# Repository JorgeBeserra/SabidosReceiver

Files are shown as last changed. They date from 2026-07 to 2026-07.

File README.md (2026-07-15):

# SabidosReceiver

Projeto de receptor e processador de áudio multicanal baseado no **PT2322-S**, controlado por um **ESP32**.

## Ferramenta

O projeto principal está em formato **KiCad 10**:

- `SabidosReceiver.kicad_pro`
- `SabidosReceiver.kicad_sch`
- `SabidosReceiver.kicad_pcb`

Abra sempre o arquivo `SabidosReceiver.kicad_pro` para manter o esquemático e a PCB associados ao mesmo projeto.

## Situação da migração

O projeto foi renomeado de `SabVolAudio` para `SabidosReceiver`. Ainda existem arquivos e identificadores legados preservados no repositório para conferência durante a migração.

Antes de removê-los definitivamente, é necessário confirmar que todas as folhas hierárquicas e todos os componentes foram convertidos corretamente para o formato atual do KiCad.

## Cuidados antes da fabricação

1. Confirmar fisicamente o encapsulamento do PT2322-S e validar o footprint em escala 1:1.
2. Abrir e salvar todas as folhas hierárquicas no KiCad 10.
3. Executar o ERC no esquemático.
4. Atualizar a PCB a partir do esquemático e revisar cada inclusão ou remoção proposta.
5. Executar o DRC na PCB.
6. Conferir a região da antena do ESP32 e manter cobre afastado.
7. Conferir polaridade dos capacitores eletrolíticos e pinagem de todos os conectores.
8. Gerar novos Gerbers somente depois da validação.

## Organização recomendada

- Arquivos `.kicad_*`: fontes atuais do projeto.
- Bibliotecas locais: símbolos e footprints necessários para abrir o projeto em outro computador.
- Modelos 3D: devem usar caminhos relativos com `${KIPRJMOD}`.
- Gerbers, backups, netlists e preferências locais não devem ser versionados.

## Observação importante

Os arquivos legados não devem ser apagados sem comparação visual com o esquemático atual, porque algumas folhas convertidas aparecem vazias e podem ainda depender do conteúdo antigo.

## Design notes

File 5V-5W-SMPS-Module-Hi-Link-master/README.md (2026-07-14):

# 5V-5W-SMPS-Module-Hi-Link
Schematic and Footptint in Kicad

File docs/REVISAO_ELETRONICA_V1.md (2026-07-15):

# Revisão eletrônica e PCB — SabidosReceiver V1

Este documento registra as alterações técnicas recomendadas antes da fabricação.

## Contexto de uso

O equipamento será usado em ambiente residencial como processador de áudio para home theater. A TV fornecerá áudio digital S/PDIF a um conversor externo, e as saídas analógicas multicanal desse conversor entrarão no SabidosReceiver.

A placa será alimentada por fonte DC regulada de 12 V para uso interno. Não é necessário projetar para transientes automotivos, load dump ou ambiente veicular.

## Prioridade crítica

### PT2322-S

- Confirmar o encapsulamento físico e a pinagem do componente disponível.
- O footprint somente deve ser substituído depois da medição do CI real.
- Imprimir o footprint em escala 1:1 e conferir o componente sobre o papel.

### Folhas hierárquicas

- `display.kicad_sch` e `Ir.kicad_sch` estão vazias na versão atual.
- Não atualizar a PCB a partir do esquemático enquanto não for decidido se esses circuitos serão recuperados dos arquivos legados ou removidos.

## Alimentação

- Manter a fonte chaveada LM2596 fisicamente afastada das entradas e saídas de áudio.
- Criar retorno de corrente curto entre entrada de 12 V, LM2596 e conector de alimentação.
- Não permitir que o retorno do conversor atravesse a região do PT2322-S.
- Adicionar desacoplamento local próximo ao PT2322-S: 100 nF cerâmico em paralelo com 10 µF na alimentação de 8 V.
- Adicionar desacoplamento próximo ao ESP32: 100 nF cerâmico e capacitor de reserva entre 220 µF e 470 µF na linha de 5 V.
- Manter o LM78M08 com área de cobre suficiente para dissipação térmica.
- Priorizar fonte externa regulada e de baixo ruído.
- Se houver ruído audível, considerar filtro LC ou regulador pós-filtro dedicado para a seção analógica.

## I²C e conversão de nível

- Manter os 2N7002 próximos ao PT2322-S.
- Usar pull-ups inicialmente de 4,7 kΩ em 3,3 V e 8 V; deixar footprints compatíveis com 10 kΩ para ajuste.
- Manter SDA e SCL curtos, paralelos somente por pequenos trechos e afastados das entradas analógicas.
- Adicionar pontos de teste para SDA, SCL, 3V3, 5V, 8V e GND.

## Áudio

- Separar fisicamente conectores de entrada, processamento e conectores de saída.
- Evitar trilhas de áudio paralelas às trilhas de alimentação chaveada.
- Usar plano de GND contínuo; não criar divisões de terra que obriguem sinais a atravessar fendas.
- Fazer o retorno dos conectores de áudio chegar à região do PT2322-S sem compartilhar caminhos estreitos com ESP32, display ou fonte.
- Manter os capacitores de acoplamento próximos aos respectivos pinos do PT2322-S.
- Identificar claramente os canais vindos do conversor S/PDIF: FL, FR, SL, SR, C e SUB.
- Evitar loops de terra entre TV, conversor S/PDIF, SabidosReceiver e amplificadores.
- Preferir conectores de entrada e saída com aterramento bem definido e cabos curtos.

## ESP32

- Manter a antena na borda da PCB.
- Criar keepout sem cobre nas duas camadas sob a antena e à frente dela.
- Evitar componentes metálicos, cabos e conectores sobre a região da antena.
- Conferir o footprint do módulo físico antes da fabricação.

## Proteção e manutenção

- Adicionar proteção contra inversão de polaridade na entrada de 12 V.
- Adicionar fusível ou polyfuse dimensionado para a placa.
- Não é necessária TVS automotiva; opcionalmente usar TVS de baixa potência para proteção contra surtos da fonte externa.
- Identificar todos os conectores na serigrafia com função e pinagem.
- Adicionar revisão da placa e nome `SabidosReceiver` na serigrafia.
- Prever ventilação no gabinete e separar fisicamente fonte, sinal e amplificadores de potência.

## Regras mínimas sugeridas

- trilha de sinal: 0,25 mm ou maior;
- alimentação de baixa corrente: 0,50 mm ou maior;
- entrada de 12 V e alimentação do LM2596: 1,0 mm ou maior;
- cobre até a borda: pelo menos 0,30 mm;
- vias comuns: diâmetro de 0,60 mm e furo de 0,30 mm ou maiores;
- evitar ilhas de cobre sem conexão.

## Estado

Este documento não autoriza fabricação por si só. O projeto somente deve ser liberado depois de ERC, DRC, conferência física dos footprints e inspeção visual dos Gerbers.

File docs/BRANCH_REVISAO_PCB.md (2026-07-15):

# Branch de revisão eletrônica e PCB

Esta branch foi criada para concentrar as alterações de circuito e layout da próxima revisão do SabidosReceiver.

## Escopo

- concluir a migração interna do nome do projeto;
- revisar encapsulamento e pinagem do PT2322-S;
- revisar alimentação de 12 V, 8 V, 5 V e 3,3 V;
- revisar conversão de nível I²C;
- criar proteção de entrada para uso automotivo;
- revisar posicionamento do LM2596 e retornos de corrente;
- criar keepout da antena do ESP32;
- adicionar pontos de teste;
- revisar regras de trilhas e vias;
- executar ERC e DRC antes da fabricação.

As alterações de geometria e roteamento devem ser conferidas visualmente no KiCad antes do merge.

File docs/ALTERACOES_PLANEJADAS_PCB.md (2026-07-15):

# Alterações planejadas para a PCB

As alterações abaixo devem ser aplicadas no KiCad com inspeção visual e DRC:

1. Keepout de cobre sob e à frente da antena do ESP32.
2. Reposicionamento do LM2596 para longe das entradas e saídas de áudio.
3. Trilhas de 12 V e alimentação do LM2596 com largura mínima de 1 mm.
4. Pontos de teste para 3V3, 5V, 8V, GND, SDA e SCL.
5. Capacitor cerâmico de 100 nF junto ao VCC do PT2322-S.
6. Capacitor de reserva de 220 µF a 470 µF junto ao ESP32.
7. Proteção de entrada com fusível, inversão de polaridade e TVS para uso automotivo.
8. Serigrafia de todos os conectores, pinagens e revisão da placa.

Nenhuma dessas mudanças deve ser enviada para fabricação sem confirmação dos footprints físicos e execução de ERC/DRC.

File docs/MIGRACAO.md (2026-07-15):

# Migração SabVolAudio → SabidosReceiver

Este documento controla a migração do projeto sem apagar circuitos ainda não conferidos.

## Estado atual

- [x] Arquivos principais renomeados para `SabidosReceiver`.
- [x] Netlist antiga removida.
- [x] Preferências locais `.kicad_prl` removidas do versionamento.
- [x] Backups, Gerbers e arquivos temporários ignorados.
- [ ] Identificador interno do projeto atualizado em todos os arquivos KiCad.
- [ ] Referências `sheetfile "SabVolAudio.kicad_sch"` eliminadas da PCB.
- [ ] Folha `display.kicad_sch` recuperada ou removida conscientemente.
- [ ] Folha `Ir.kicad_sch` recuperada ou removida conscientemente.
- [ ] Bibliotecas locais renomeadas e validadas.
- [ ] Modelos 3D migrados para caminhos `${KIPRJMOD}`.
- [ ] Arquivos legados removidos após comparação visual.

## Procedimento seguro no KiCad

1. Criar uma cópia externa da pasta do projeto.
2. Abrir `SabidosReceiver.kicad_pro` no KiCad 10.
3. Abrir cada folha hierárquica e salvar.
4. Comparar `display.sch` com `display.kicad_sch`.
5. Comparar `Ir.sch`, quando existir, com `Ir.kicad_sch`.
6. Recuperar os circuitos ausentes antes de excluir os arquivos antigos.
7. Executar **Ferramentas → Atualizar PCB a partir do esquemático**.
8. Não aceitar remoções automáticas sem conferir referência por referência.
9. Salvar o esquemático e a PCB.
10. Fechar e reabrir o projeto para confirmar os vínculos.

## Critério para apagar arquivos legados

Um arquivo antigo só pode ser removido quando:

- o circuito equivalente existir no formato atual;
- a comparação visual estiver concluída;
- nenhum símbolo ou footprint depender da biblioteca antiga;
- o ERC não acusar folhas ou símbolos ausentes;
- a atualização da PCB não remover componentes válidos;
- o DRC não apresentar conexões pendentes provocadas pela migração.

## Comando de auditoria

Execute na raiz do repositório:

```bash
bash scripts/auditar-projeto.sh
```

O script procura referências antigas, caminhos absolutos e folhas hierárquicas aparentemente vazias.

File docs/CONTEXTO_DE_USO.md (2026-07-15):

# Contexto de uso — SabidosReceiver

O SabidosReceiver será utilizado em ambiente residencial, como processador de áudio para home theater.

## Cadeia de sinal prevista

1. TV com saída digital S/PDIF;
2. conversor externo S/PDIF para áudio analógico multicanal;
3. entradas analógicas do SabidosReceiver;
4. processamento e controle de volume pelo PT2322-S;
5. saídas para amplificadores de potência do sistema de caixas acústicas.

## Consequências para o projeto

- a alimentação não precisa atender transientes automotivos;
- não é necessária TVS automotiva nem proteção específica contra load dump;
- continuam recomendados fusível, proteção contra inversão de polaridade e filtragem de entrada;
- a prioridade passa a ser baixo ruído, baixa ondulação da alimentação, aterramento adequado e redução de interferência da fonte chaveada;
- o LM2596 deve permanecer fisicamente afastado das entradas analógicas e do PT2322-S;
- conectores de entrada devem ser identificados conforme os canais entregues pelo conversor S/PDIF;
- o gabinete deve prever ventilação, aterramento e separação física entre fonte, circuito de sinal e amplificadores.

## Premissa elétrica

A entrada prevista é uma fonte DC regulada de 12 V para uso interno. A corrente necessária deve ser confirmada considerando ESP32, display, PT2322-S, relés e demais periféricos; os amplificadores de potência devem preferencialmente usar alimentação própria.

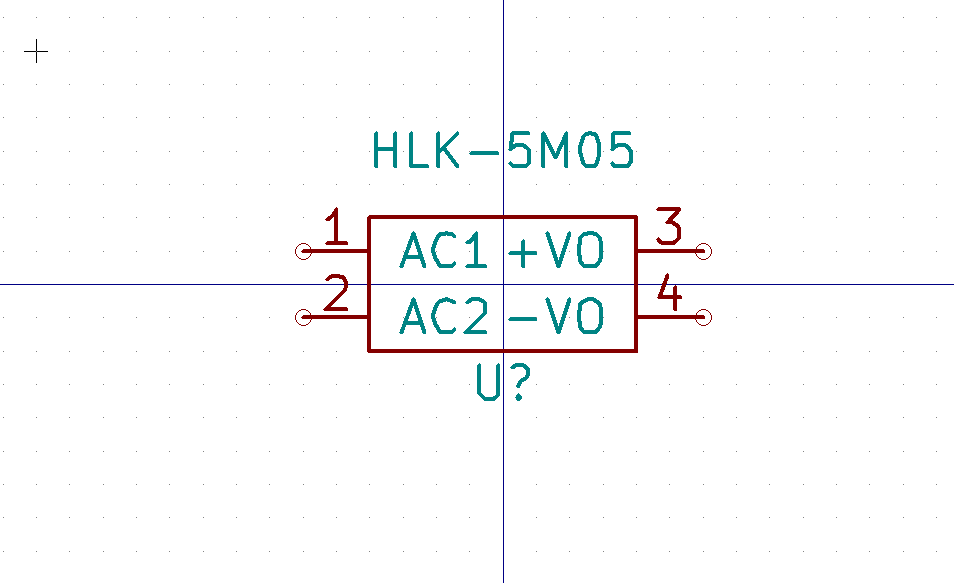
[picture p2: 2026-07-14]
5V-5W-SMPS-Module-Hi-Link-master/HLK-5M05.png

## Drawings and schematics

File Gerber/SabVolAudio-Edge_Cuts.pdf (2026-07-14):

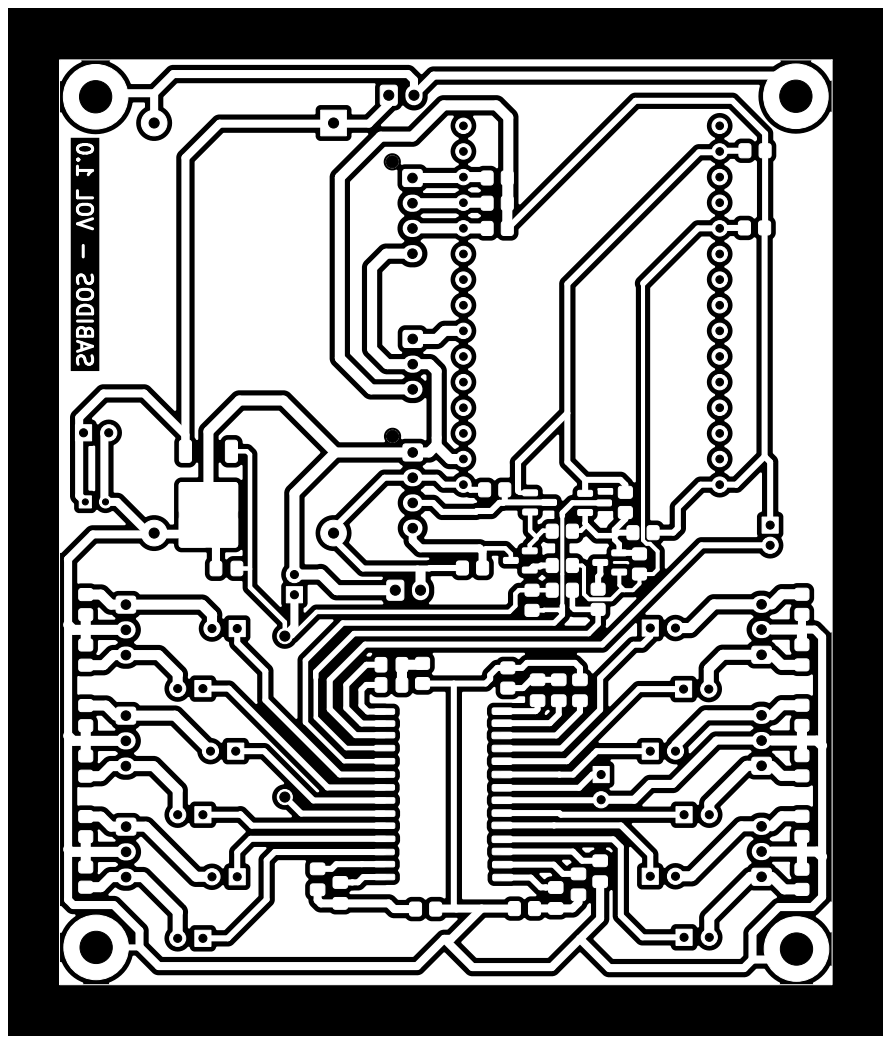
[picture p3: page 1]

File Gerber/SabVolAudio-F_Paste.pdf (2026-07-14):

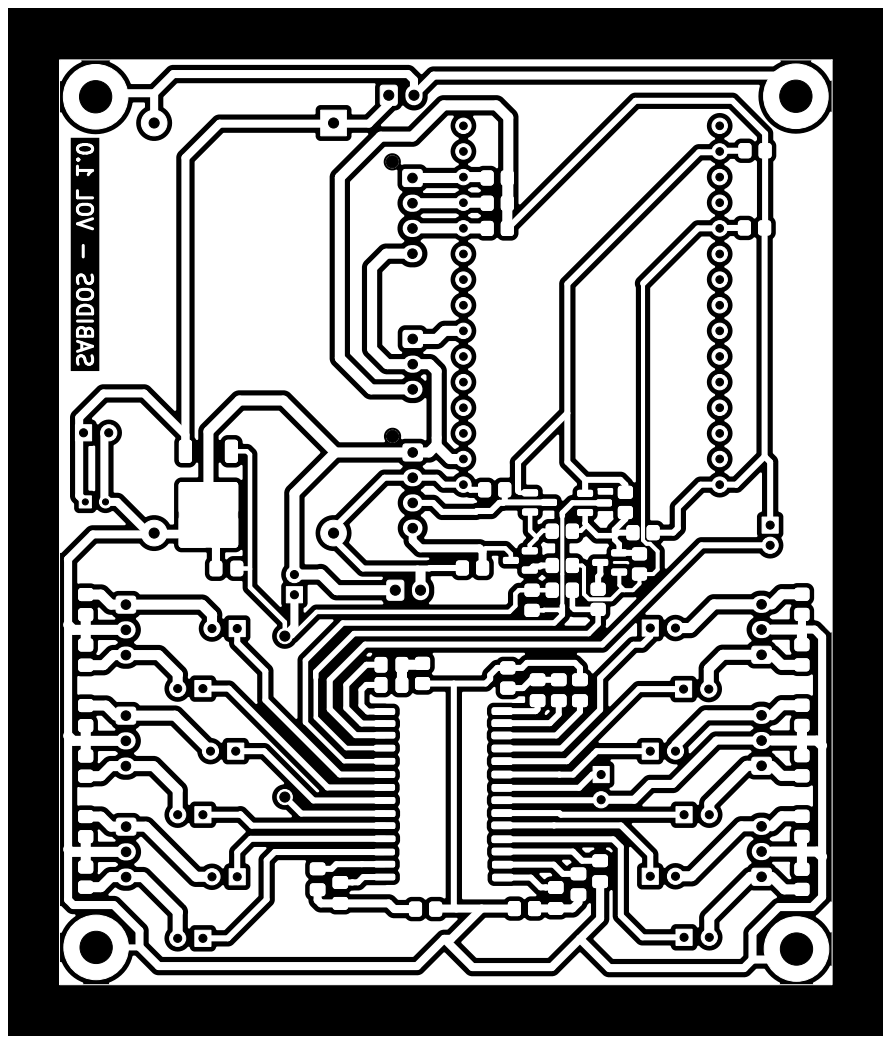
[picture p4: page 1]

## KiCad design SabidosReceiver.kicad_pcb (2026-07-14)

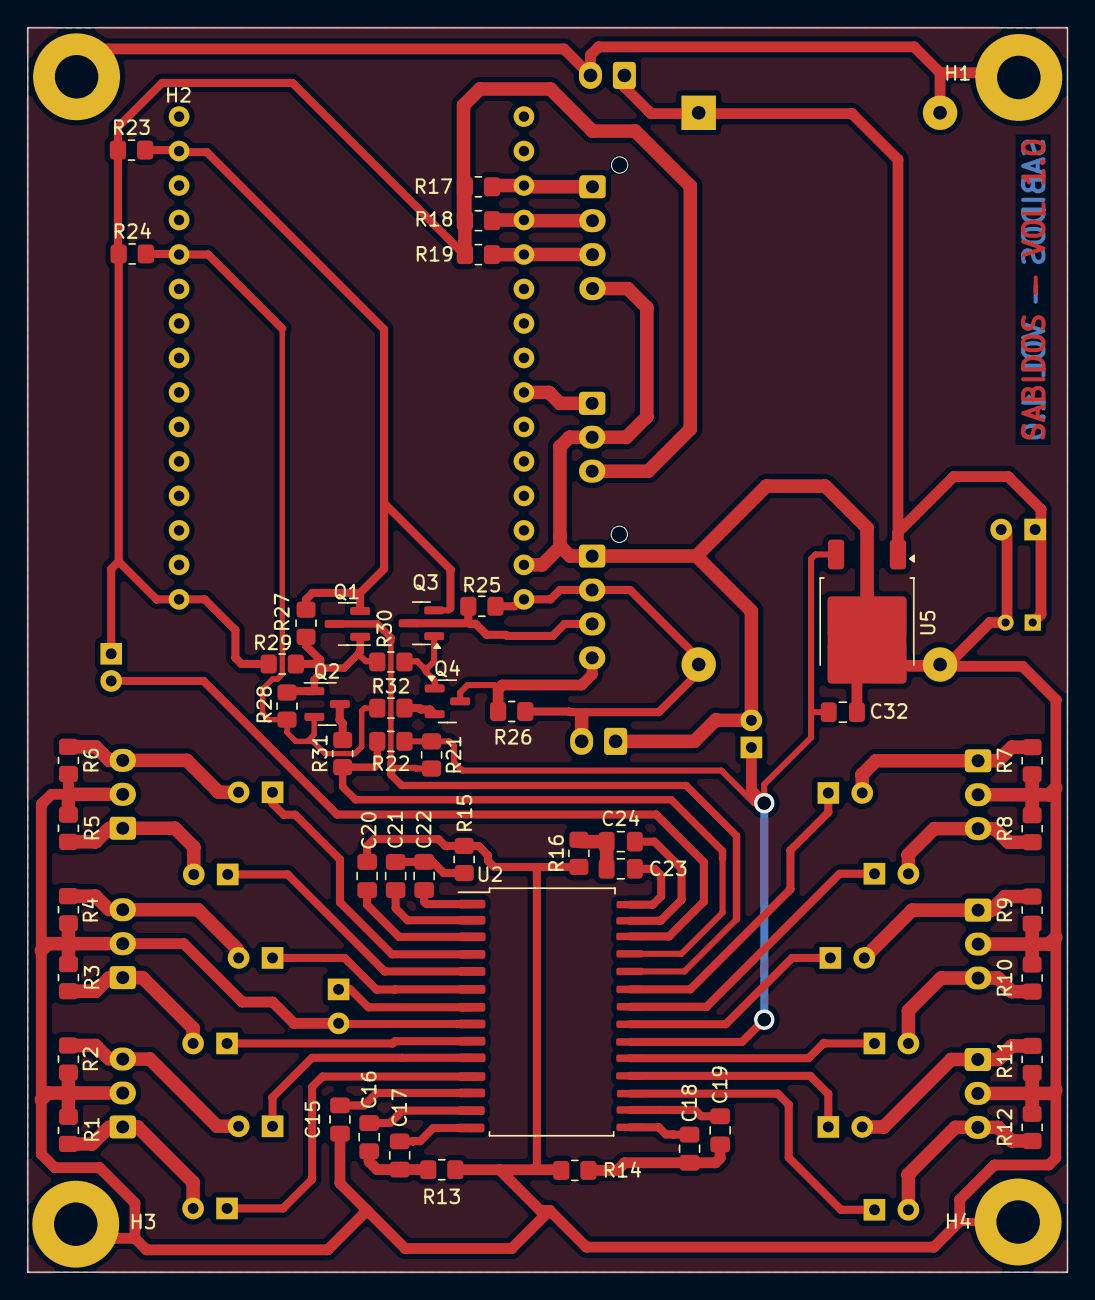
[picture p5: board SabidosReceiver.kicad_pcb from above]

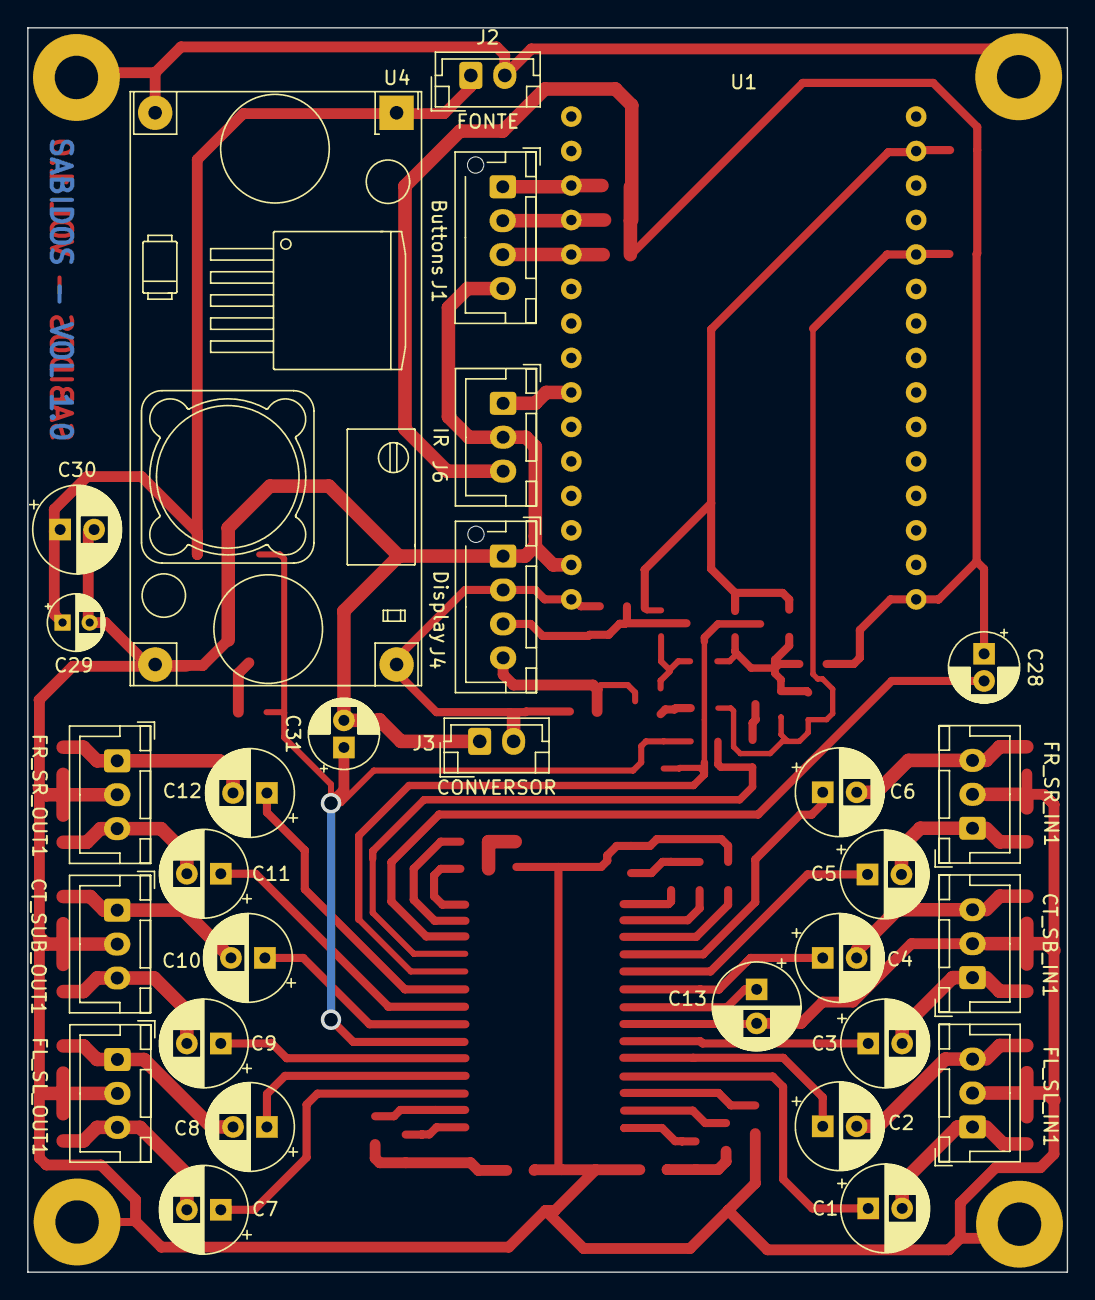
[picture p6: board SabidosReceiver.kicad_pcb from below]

Board: 2 copper layers, 76.6 x 91.7 mm, 82 parts (30 on the bottom side), 58 nets.

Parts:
C1, C2, C3, C4, C5, C6, C7, C8, C9, C10, C11, C12, C13: 10uF; CP_Radial_D6.3mm_P2.50mm
C15, C20: 2200pF; C_0805_2012Metric_Pad1.18x1.45mm_HandSolder
C16, C17, C21, C22: 0.01uF; C_0805_2012Metric_Pad1.18x1.45mm_HandSolder
C18, C19, C23, C24: 0.1uF; C_0805_2012Metric_Pad1.18x1.45mm_HandSolder
C28: 10MFD; CP_Radial_D5.0mm_P2.00mm
C29: 22uF; CP_Radial_D4.0mm_P2.00mm
C30: 100MFD; CP_Radial_D6.3mm_P2.50mm
C31: 22MFD; CP_Radial_D5.0mm_P2.00mm
C32: 0.1MFD; C_0805_2012Metric_Pad1.18x1.45mm_HandSolder
CT_SB_IN1: Conn_01x03_Pin; JST_XH_B3B-XH-A_1x03_P2.50mm_Vertical
CT_SUB_OUT1: Conn_01x03_Pin; JST_XH_B3B-XH-A_1x03_P2.50mm_Vertical
FL_SL_IN1: Conn_01x03_Pin; JST_XH_B3B-XH-A_1x03_P2.50mm_Vertical
FL_SL_OUT1: Conn_01x03_Pin; JST_XH_B3B-XH-A_1x03_P2.50mm_Vertical
FR_SR_IN1: Conn_01x03_Pin; JST_XH_B3B-XH-A_1x03_P2.50mm_Vertical
FR_SR_OUT1: Conn_01x03_Pin; JST_XH_B3B-XH-A_1x03_P2.50mm_Vertical
H1, H2, H3, H4: M3; MountingHole_3.2mm_M3_Pad
J1: Buttons; JST_XH_B4B-XH-AM_1x04_P2.50mm_Vertical
J2: FONTE; JST_EH_B2B-EH-A_1x02_P2.50mm_Vertical
J3: CONVERSOR; JST_EH_B2B-EH-A_1x02_P2.50mm_Vertical
J4: Display; JST_XH_B4B-XH-AM_1x04_P2.50mm_Vertical
J6: IR; JST_XH_B3B-XH-A_1x03_P2.50mm_Vertical
Q1, Q2, Q3, Q4: 2N7002; SOT-23
R1, R2, R3, R4, R5, R6, R7, R8, R9, R10, R11, R12: 100k; R_0805_2012Metric_Pad1.20x1.40mm_HandSolder
R13, R15: 3.3k; R_0805_2012Metric_Pad1.20x1.40mm_HandSolder
R14, R16: 6.2k; R_0805_2012Metric_Pad1.20x1.40mm_HandSolder
R17, R18, R21, R22, R23, R24, R25, R26, R27, R28: 10K; R_0805_2012Metric_Pad1.20x1.40mm_HandSolder
R19: 10K3; R_0805_2012Metric_Pad1.20x1.40mm_HandSolder
R29, R30, R31, R32: 0K; R_0805_2012Metric_Pad1.20x1.40mm_HandSolder
U1: DOIT-ESP32-DEVKIT-V1; ESP32-DOIT-DEVKIT
U2: PT2322-S; SOP-28_7.5x15.4mm_P1.27mm
U4: LM2596; YAAJ_DCDC_StepDown_LM2596
U5: LM78M08; TO-252-2

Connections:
+3V3: C28.1, J6.3, R17.1, R18.1, R19.1, R23.1, R24.1, R29.1, U1.16 (3V3)
+3V3-0: Q1.1 (G), Q2.1 (G), R27.1, R28.1, R29.2, R30.1
+3V3-1: Q3.1 (G), Q4.1 (G), R30.2
+5V: J3.2, J4.2, R25.1, R26.1, U1.15 (5V), U4.4 (Vout)
+8V: C31.1, C32.1, R21.1, R22.1, U2.20 (VCC), U5.3 (VO)
+12V: C29.1 (+), C30.1, J2.1, U4.1 (Vin), U5.1 (VI)
/Processador/SCL-HV-5V: J4.3, Q3.3 (D), R25.2
/Processador/SDA-HV-5V: J4.4, Q4.3 (D), R26.2
GNDD: C13.2 (-), C15.2, C20.1, C28.2, C29.2 (-), C30.2, C31.2, C32.2, CT_SB_IN1.2, CT_SUB_OUT1.2, FL_SL_IN1.2, FL_SL_OUT1.2, FR_SR_IN1.2, FR_SR_OUT1.2, H1.1, H2.1, H3.1, H4.1, J1.4, J2.2, J3.1, J4.1, J6.2, R1.2, R2.2, R3.2, R4.2, R5.2, R6.2, R7.2, R8.2, R9.2, R10.2, R11.2, R12.2, R13.2, R14.2, R15.1, R16.1, U1.14 (GND), U1.17 (GND), U2.8 (GND), U2.26 (DGND), U4.2 (GND), U4.3 (GND), U5.2 (GND)
GPIO26: J6.1, U1.9 (GPIO26_ADC2-CH9_DAC2_RTC-GPIO7)
unnamed: C1.1 (+), U2.11 (IN_FL)
unnamed: C1.2 (-), FL_SL_IN1.1, R1.1
unnamed: C2.1 (+), U2.10 (IN_SL)
unnamed: C2.2 (-), FL_SL_IN1.3, R2.1
unnamed: C3.1 (+), U2.9 (IN_CT)
unnamed: C3.2 (-), CT_SB_IN1.1, R3.1
unnamed: C4.1 (+), U2.6 (IN_SUB)
unnamed: C4.2 (-), CT_SB_IN1.3, R4.1
unnamed: C5.1 (+), U2.5 (IN_SR)
unnamed: C5.2 (-), FR_SR_IN1.1, R5.1
unnamed: C6.1 (+), U2.4 (IN_FR)
unnamed: C6.2 (-), FR_SR_IN1.3, R6.1
unnamed: C7.1 (+), U2.17 (OUT_FL)
unnamed: C7.2 (-), FL_SL_OUT1.3, R12.1
unnamed: C8.1 (+), U2.18 (OUT_SL)
unnamed: C8.2 (-), FL_SL_OUT1.1, R11.1
unnamed: C9.1 (+), U2.19 (OUT_CT)
unnamed: C9.2 (-), CT_SUB_OUT1.3, R10.1
unnamed: C10.1 (+), U2.21 (OUT_SUB)
unnamed: C10.2 (-), CT_SUB_OUT1.1, R9.1
unnamed: C11.1 (+), U2.22 (OUT_SR)
unnamed: C11.2 (-), FR_SR_OUT1.3, R8.1
unnamed: C12.1 (+), U2.23 (OUT_FR)
unnamed: C12.2 (-), FR_SR_OUT1.1, R7.1
unnamed: C13.1 (+), U2.7 (VREF)
unnamed: C16.2, C17.2, R13.1
unnamed: C18.2, C19.2, R14.1
unnamed: C21.1, C22.1, R15.2
unnamed: C23.1, C24.1, R16.2
unnamed: J1.1, R17.2, U1.3 (GPIO39_ADC1-CH3_SENS-VN_RTC-GPIO3)
unnamed: J1.2, R18.2, U1.4 (GPIO34_ADC1-CH6_RTC-GPIO4)
unnamed: J1.3, R19.2, U1.5 (GPIO35_ADC1-CH7_RTC-GPIO5)
unnamed: Q2.3 (D), R31.2
unnamed: Q4.2 (S), R32.1
unnamed: C15.1, U2.12 (CTRE_FL)
unnamed: C20.2, U2.3 (CTRE_FR)
unnamed: C18.1, U2.15 (RCBAS1_FL)
unnamed: C23.2, U2.28 (RCBAS1_FR)
unnamed: C19.1, U2.16 (RCBAS2_FL)
unnamed: C24.2, U2.27 (RCBAS2_FR)
unnamed: C21.2, U2.2 (RCMID1)
unnamed: C16.1, U2.13 (RCMID1_FL)
unnamed: C22.2, U2.1 (RCMID2)
unnamed: C17.1, U2.14 (RCMID2_FL)
SCL-3V: Q1.2 (S), Q3.2 (S), R23.2, R27.2, U1.29 (GPIO22_I2C-SCL)
SCL-HV-8V: Q1.3 (D), R21.2, U2.24 (SCL)
SDA-3V: Q2.2 (S), R24.2, R28.2, R32.2, U1.26 (GPIO21_I2C-SDA)
SDA-HV-8V: R22.2, R31.1, U2.25 (SDA)

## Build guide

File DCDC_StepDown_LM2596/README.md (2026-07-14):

KiCad library for the LM2596 buck/step-down module

3D models come in two formats : STEP and WRL, in a ZIP archive, files being too large for GitHub.

3D models : bare module, and model with pin headers



Symbol :



Footprint :



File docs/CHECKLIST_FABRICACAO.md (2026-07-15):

# Checklist antes da fabricação

## Esquemático

- [ ] ERC executado sem erros não justificados.
- [ ] Todas as folhas hierárquicas abrem corretamente.
- [ ] PT2322-S conferido pino a pino com o datasheet e com o componente físico.
- [ ] Polaridade de todos os eletrolíticos conferida.
- [ ] Pinagem e orientação de todos os conectores conferidas.
- [ ] Barramento I²C validado entre 3,3 V e 8 V.
- [ ] Pull-ups do I²C revisados e documentados.
- [ ] Entradas não utilizadas possuem tratamento definido.
- [ ] Pontos de teste adicionados para `+12V`, `+8V`, `+5V`, `+3V3`, GND, SDA e SCL.

## PCB

- [ ] DRC executado sem erros não justificados.
- [ ] Footprint do PT2322-S validado em impressão 1:1.
- [ ] Footprint do módulo ESP32 medido no hardware real.
- [ ] Antena do ESP32 sem cobre nas duas camadas e afastada de metal.
- [ ] LM2596 afastado das entradas e trilhas de áudio.
- [ ] Correntes de retorno da fonte não atravessam a região analógica.
- [ ] Plano de terra contínuo e sem gargalos.
- [ ] Trilhas de alimentação dimensionadas para a corrente prevista.
- [ ] Cobre afastado da borda conforme a capacidade da fabricante.
- [ ] Furos de montagem e áreas mecânicas conferidos.
- [ ] Serigrafia não cobre pads e indica polaridade/pino 1.

## Arquivos de produção

- [ ] Gerbers regenerados a partir da revisão aprovada.
- [ ] Arquivo de furação regenerado.
- [ ] Gerbers inspecionados em visualizador independente.
- [ ] Camadas, espessura e acabamento definidos.
- [ ] BOM revisada.
- [ ] Arquivo de posição revisado, quando houver montagem automática.
- [ ] Revisão da placa gravada na serigrafia.
- [ ] Hash ou tag Git da versão de fabricação registrado.

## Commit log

2026-07-15 chore: adiciona regras de limpeza do projeto KiCad
2026-07-15 chore: remove netlist legada gerada pelo KiCad 5
2026-07-15 chore: remove preferências locais do KiCad
2026-07-15 Adiciona regras de atributos para arquivos KiCad
2026-07-15 Adiciona auditoria estática do projeto KiCad
2026-07-15 Adiciona checklist de fabricação da placa
2026-07-15 Adiciona auditoria automática do projeto KiCad
2026-07-15 docs: adiciona plano de revisão eletrônica e PCB
2026-07-15 chore: adiciona migração segura de nomes internos do KiCad
2026-07-15 docs: registra alterações planejadas para PCB
2026-07-15 docs: inicia branch de revisão eletrônica e PCB
2026-07-15 Ajusta revisão eletrônica para uso residencial
2026-07-16 Documenta revisão do caminho PT2323 para PT2322
2026-07-16 Adiciona regras DRC para alimentações e barramento I2C
2026-07-16 Ajusta largura mínima de trilhas para 0,50 mm
